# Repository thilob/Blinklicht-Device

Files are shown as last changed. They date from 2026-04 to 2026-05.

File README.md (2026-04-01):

# ESP32 Blaulicht-Controller mit Web-UI & CLI

Dieses Projekt ist ein **Blaulicht-Controller für Modellbau und ähnliche Anwendungen**.  
Die Software läuft auf verschiedenen ESP32-Boards und nutzt die jeweils vorhandenen **LEDC-PWM-Kanäle** der Zielhardware.  

---

## Features

- Bis zur **hardwareabhaengigen LEDC-Grenze** des jeweiligen ESP32-Ziels (PWM, 5 kHz, 8 Bit Helligkeit)  
- **Mehrere Blinkmuster (Patterns)**, die frei definierbar sind  
- **Gruppen-Funktion**: LEDs lassen sich zu Gruppen zusammenfassen und gemeinsam ein-/ausschalten  
- **Phasenverschiebung**: gleiche Muster können zeitlich versetzt starten  
- **Weboberfläche (GUI)**: läuft direkt im Browser (Handy, Tablet, PC), responsive gestaltet  
- **Serielle Konsole (CLI)**: alle Funktionen auch über USB-Terminal steuerbar  
- **Speicherung im Flash** (LittleFS): Konfiguration überlebt Neustarts  
- **WLAN-Betrieb**: Access Point (AP) oder Station (STA, DHCP) mit mDNS (z. B. `http://blaulicht-xxxx.local`)  
- **Captive Portal**: Im AP-Modus wird die Weboberfläche automatisch geöffnet  
- **Brownout-Schutz**: externe Kondensatoren empfohlen (siehe unten)  

---

## Hardware-Aufbau

### ESP32-DevKit
- Verwendet wird ein Standard-ESP32-DevKit (mit USB-Anschluss und Spannungsregler).  

### LED-Ausgänge
- PWM ist nicht auf "ein paar Spezialpins" begrenzt, sondern kann auf viele ausgabefaehige GPIOs gemappt werden.  
- Die eigentliche Grenze ist die Anzahl gleichzeitig verfuegbarer **LEDC-Kanaele** der jeweiligen ESP32-Variante.  
- Das Projekt begrenzt die Standard-Konfiguration automatisch auf die LEDC-Kapazitaet der gewaehlten Zielhardware.  
- Jeder Ausgang steuert eine LED oder LED-Baugruppe.  
- Vor jede LED gehört ein **Vorwiderstand** (typisch 220–470 Ω bei 5 V Betrieb).  

### Versorgung & Brownout-Schutz
Der ESP32 ist empfindlich gegenüber Spannungseinbrüchen („Brownout“).  
Das passiert besonders dann, wenn mehrere LEDs gleichzeitig leuchten oder wenn das WLAN viel Strom zieht.

👉 Deshalb unbedingt folgende Maßnahmen:
- **Ein großer Elektrolytkondensator** (470 µF bis 1000 µF, 6,3 V oder mehr) **zwischen 3,3 V und GND**, möglichst nah am ESP32 bzw. am `3V3`-Pin des Devkits.  
- **Ein Keramikkondensator** (100 nF) direkt am Board bzw. an `3V3`/`GND` als schnelle Stütze.  
- Wenn die Schaltung über USB versorgt wird und die LED-Last die `5V`-Schiene stark belastet, zusätzlich ein weiterer Elko **zwischen `USB 5V` und `GND`** nahe am Devkit oder an der Last.  

So werden Spannungsschwankungen abgefangen und der ESP32 läuft stabil.

---

## Schaltplan (vereinfacht)

### Prinzipdarstellung (ASCII)

```  
USB 5V ----+-----------------------------+
           |                             |
      [DevKit-Regler 3.3V]               |
           |                             |
          3V3 ---+---- ESP32             |
                 |      +-----+-----+    |
             [470uF]    |           |    |
                 |  GPIOx       GPIOy ...|
                GND  |            |      |
                    [R]          [R]     |
                     |            |      |
                    LED          LED     |
                     |            |      |
GND -----------------+------------+------+

Optional bei hoher LED-Last auf USB/5V:

USB 5V ---+--- [zus. Elko 470uF..1000uF] --- GND
```

- `[R]` = Vorwiderstand (220–470 Ω)  
- `[470uF]` = Pufferkondensator zwischen `3.3V` und `GND` gegen Brownouts  
- `[zus. Elko 470uF..1000uF]` = optionaler Puffer zwischen `USB 5V` und `GND`, wenn die `5V`-Versorgung durch LED-Last stark einbricht  

---

## Software-Prinzip

### Patterns (Blinkmuster)
Ein **Pattern** ist eine Liste von Schritten:
- `duration_ms` – Dauer in Millisekunden  
- `level` – Ziel-Helligkeit (0..255)  
- `fade` – weicher Übergang (true) oder harter Sprung (false)  

Beispiel für ein Doppelblitz-Pattern:

```cpp
{30, 255, false},  // LED an
{30,   0, false},  // aus
{30, 255, false},  // LED an
{150, 0,  true},   // langsam ausblenden
{250, 0,  false},  // Pause
```

- Der **letzte Schritt ist die Pause**, bevor das Muster neu startet.  
- Pro Ausgang kann das Pattern individuell gewählt werden.  
- Jeder Ausgang kann zusätzlich eine **Zusatzpause** bekommen, die auf den letzten Schritt des Patterns aufaddiert wird.  

### Gruppen
- Mehrere Ausgänge können zu **Gruppen** zusammengefasst werden.  
- Eine Gruppe kann komplett **ein- oder ausgeschaltet** werden.  
- Ist eine Gruppe aus, bleiben die LEDs dunkel (das Pattern pausiert).  

---

## CLI (Serielle Konsole)

Über USB (115200 Baud) öffnet sich ein Terminal.  
Man sieht, was man tippt (Echo-Funktion ist aktiv).

### Wichtige Befehle:

- `help` → alle Befehle anzeigen  
- `status` → Status von WLAN, Patterns, Gruppen und Ausgängen  
- `wifi on|off` → WLAN/Webserver ein-/ausschalten  
- `mode ap|sta` → WLAN-Modus wählen  
- `sta <ssid> <pass>` → Zugangsdaten für Station-Modus setzen  
- `ap <ssid> [pass]` → SSID/PW für Access Point setzen  
- `dhcp` → im STA-Modus neue DHCP-Adresse beziehen  
- `pat list` → Patterns anzeigen  
- `pat add <name>` → neues Pattern anlegen  
- `pat step add <pidx> <dur> <lvl> <fade>` → Step zu Pattern hinzufügen  
- `group list` → Gruppen anzeigen  
- `group add <id> <name>` → Gruppe anlegen  
- `light list` → Ausgänge anzeigen  
- `light add <pin> <ch> <pidx> <zusatzpause> <gid> <phase>` → Ausgang hinzufügen  

---

## Weboberfläche (GUI)

Die **Web-UI** wird aus dem Flash geladen (`LittleFS`).  
- Im AP-Modus erreichbar unter: `http://192.168.4.1`  
  (Captive Portal öffnet die Seite oft automatisch)  
- Im STA-Modus unter: `http://<hostname>.local` oder über die vergebene DHCP-IP  

### Funktionen:
- WLAN konfigurieren (AP oder STA)  
- Patterns anlegen, bearbeiten, löschen  
- Gruppen verwalten und schalten  
- Ausgänge (Lights) hinzufügen, ändern, löschen  

Die Oberfläche ist **responsive** (Bootstrap-Layout) → funktioniert gut auf Handy, Tablet und PC.  

---

## Build & Flash (PlatformIO)

1. Projekt in **VS Code / PlatformIO** öffnen  
2. **Build** → Firmware kompilieren  
3. **Upload** → ESP32 flashen  
4. **Upload Filesystem Image** → Weboberfläche (index.html) ins LittleFS laden  
5. Serielle Konsole (115200 Baud) starten → Logausgaben prüfen  

### CLI-Beispiele

```bash
# Firmware für ESP32 DevKit V1 / ESP32-WROOM bauen
$HOME/.platformio/penv/bin/pio run -e devkit-v1

# Firmware hochladen
$HOME/.platformio/penv/bin/pio run -e devkit-v1 -t upload

# LittleFS-Image hochladen
$HOME/.platformio/penv/bin/pio run -e devkit-v1 -t uploadfs
```

### Upload-Port / udev-Hinweise unter Linux

Beim Upload kann PlatformIO z. B. folgende Meldungen anzeigen:

```text
Looking for upload port...

Warning! Please install `99-platformio-udev.rules`.
More details: https://docs.platformio.org/en/latest/core/installation/udev-rules.html

Auto-detected: /dev/ttyS0
Uploading .pio/build/devkit-v1/littlefs.bin
esptool.py v4.11.0
Serial port /dev/ttyS0
```

Das bedeutet meist:
- Die empfohlenen PlatformIO-`udev`-Regeln für USB-Seriell-Geräte sind noch nicht installiert.
- PlatformIO hat vermutlich den falschen Port erkannt.
- `/dev/ttyS0` ist oft **nicht** der USB-Port des ESP32, sondern eine interne serielle Schnittstelle des PCs.

Prüfe in so einem Fall die tatsächlich vorhandenen USB-Ports, z. B.:

```bash
ls /dev/ttyUSB* /dev/ttyACM* 2>/dev/null
```

Und gib den Upload-Port dann explizit an:

```bash
$HOME/.platformio/penv/bin/pio run -e devkit-v1 -t upload --upload-port /dev/ttyUSB0
$HOME/.platformio/penv/bin/pio run -e devkit-v1 -t uploadfs --upload-port /dev/ttyUSB0
```

Wenn du unter Linux häufiger Upload-Probleme oder Zugriffsfehler auf serielle Geräte hast, installiere die PlatformIO-`udev`-Regeln:
- Doku: https://docs.platformio.org/en/latest/core/installation/udev-rules.html

### Richtigen Port beim Einstecken finden

Wenn unklar ist, welches Device zu deinem ESP32 gehört, öffne vor dem Einstecken ein Kernel-Log:

```bash
journalctl -k -f
```

Alternativ:

```bash
dmesg --follow
```

Stecke dann den ESP32 an. Typische Meldungen nennen danach den neu angelegten Port, z. B.:

```text
cdc_acm 1-1.3:1.0: ttyACM0: USB ACM device
```

oder:

```text
ch341-uart converter now attached to ttyUSB0
```

Diesen Port kannst du anschließend direkt für Upload und Monitor verwenden:

```bash
$HOME/.platformio/penv/bin/pio run -e devkit-v1 -t upload --upload-port /dev/ttyACM0
$HOME/.platformio/penv/bin/pio device monitor --port /dev/ttyACM0 --baud 115200
```

---

## Fazit

Mit diesem Projekt erhältst du eine **flexible Steuerung für Modellbau-Blaulichter**:  
- Komfortabel über **Web-GUI**  
- Alternativ robust über **CLI**  

Dank externer **Pufferkondensatoren** läuft der ESP32 stabil, auch wenn mehrere LEDs gleichzeitig blinken.  
Die Software ist modular aufgebaut und lässt sich leicht erweitern.

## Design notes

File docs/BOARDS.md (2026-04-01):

# Board-Konfigurationssystem

## Übersicht

Dieses Projekt unterstützt verschiedene ESP32-Boards mit unterschiedlichen Pin-Konfigurationen. Die Board-Konfiguration erfolgt automatisch basierend auf dem gewählten PlatformIO Environment. Die maximal gleichzeitig nutzbaren PWM-Ausgaenge richten sich nach den LEDC-Kanaelen der jeweiligen ESP32-Zielhardware.

## Unterstützte Boards

### ESP32 DevKit (Standard)
- **Environment:** `esp32dev`
- **Alias:** `devkit-v1`
- **Vorkonfigurierte Ausgänge:** 10 LEDs
- **Max. gleichzeitige PWM-Kanaele:** 16
- **Pins:** GPIO 16, 17, 18, 19, 21, 22, 23, 25, 26, 27
- **Reset Pin:** GPIO 34

### ESP32-C3 DevKit M1
- **Environment:** `esp32-c3-devkitm-1`
- **Vorkonfigurierte Ausgänge:** 8 LEDs
- **Max. gleichzeitige PWM-Kanaele:** 8
- **Pins:** GPIO 2, 3, 4, 5, 6, 7, 8, 9
- **Reset Pin:** GPIO 10
- **Hinweis:** GPIO 0,1 für USB reserviert

### ESP32-C3 Super Mini
- **Environment:** `esp32c3-super-mini`
- **Vorkonfigurierte Ausgänge:** 8 LEDs
- **Max. gleichzeitige PWM-Kanaele:** 8
- **Pins:** GPIO 2, 3, 4, 5, 6, 7, 8, 9
- **Reset Pin:** GPIO 10
- **Hinweis:** Sehr kompaktes Board

### WiFiduino32 C3
- **Environment:** `wifiduino32c3`
- **Vorkonfigurierte Ausgänge:** 8 LEDs
- **Hinweis:** 10 Pins sind hinterlegt, aber der ESP32-C3 stellt gleichzeitig nur 8 LEDC-PWM-Kanaele bereit.
- **Pins:** GPIO 2, 3, 4, 5, 6, 7, 8, 9, 10, 18
- **Reset Pin:** GPIO 19

### ESP32-S2 Mini
- **Environment:** `esp32s2-mini`
- **Vorkonfigurierte Ausgänge:** 8 LEDs
- **Hinweis:** 12 Pins sind hinterlegt, gleichzeitig nutzbar sind aber 8 LEDC-PWM-Kanaele.
- **Pins:** GPIO 1-12
- **Reset Pin:** GPIO 0

### ESP32-S3 DevKit
- **Environment:** `esp32s3-devkit`
- **Vorkonfigurierte Ausgänge:** 8 LEDs
- **Hinweis:** 16 Pins sind hinterlegt, gleichzeitig nutzbar sind aber 8 LEDC-PWM-Kanaele.
- **Pins:** GPIO 1-16
- **Reset Pin:** GPIO 0
- **Hinweis:** Mehr GPIOs verfügbar

## Verwendung

### 1. Board auswählen in VS Code

In VS Code unten in der Statusleiste auf das PlatformIO-Symbol klicken und das gewünschte Environment auswählen, z.B. `esp32dev` oder `devkit-v1`.

### 2. Mit PlatformIO CLI

```bash
# ESP32 DevKit kompilieren
pio run -e esp32dev

# ESP32 DevKit V1 (ESP32-WROOM) kompilieren
pio run -e devkit-v1

# ESP32-C3 kompilieren und uploaden
pio run -e esp32-c3-devkitm-1 -t upload

# ESP32-S3 kompilieren und Monitor starten
pio run -e esp32s3-devkit -t upload -t monitor
```

### 3. Board-Info beim Start

Beim Booten zeigt der Serial Monitor die aktuelle Board-Konfiguration:

```
========================================
Blaulicht-Controller (Multi-Board)
========================================
Board:         ESP32 DevKit
LED Ausgänge:  10
LEDC Kanäle:   16
Reset Pin:     GPIO 34
========================================
```

## Eigenes Board hinzufügen

### Schritt 1: Board-Definition in `board_config.h`

```cpp
#elif defined(BOARD_MEIN_BOARD)
  #define BOARD_NAME "Mein Custom Board"

  static const int LED_PINS[] = {
    13, 14, 15, 16, 17, 18  // Deine Pins
  };
  
  static const int RESET_WIFI_PIN = 12;
```

### Schritt 2: Environment in `platformio.ini`

```ini
[env:mein-board]
platform = espressif32
board = esp32dev  ; oder passende Board-ID
framework = arduino
monitor_speed = 115200
board_build.filesystem = littlefs

lib_deps = ${common.lib_deps}

build_flags =
  ${common.base_flags}
  -DBOARD_MEIN_BOARD  ; <-- Wichtig!

lib_ldf_mode = deep+
```

### Schritt 3: Kompilieren

```bash
pio run -e mein-board -t upload
```

## Pin-Auswahl Tipps

### ESP32 (Original)
- ✅ Sicher: GPIO 2, 4, 5, 12-19, 21-23, 25-27, 32-33
- ⚠️ Input-Only: GPIO 34-39 (nur als Eingänge)
- ❌ Vermeiden: GPIO 0, 1 (Boot/Flash), 6-11 (Flash)

### ESP32-C3
- ✅ Sicher: GPIO 2-10, 18-21
- ❌ Vermeiden: GPIO 0, 1 (USB), 18, 19 wenn USB benötigt

### ESP32-S2
- ✅ Sicher: GPIO 1-14, 15-17, 33-42
- ❌ Vermeiden: GPIO 0 (Boot), 19-20 (USB)

### ESP32-S3
- ✅ Viele GPIOs verfügbar
- ❌ Vermeiden: GPIO 19-20 (USB), 26-32 (PSRAM wenn genutzt)

## Beispiel: Migration von einem Board zum anderen

Wenn du von ESP32 DevKit auf ESP32-C3 wechseln möchtest:

1. **Umstecken der Hardware:** Verbinde deine LEDs mit den Pins aus `board_config.h`
2. **Environment wählen:** `esp32-c3-devkitm-1` in PlatformIO
3. **Upload:** Der Code kompiliert automatisch mit den richtigen Pins!
4. **Config prüfen:** Falls du bereits eine `config.json` hast, prüfe ob die Pins stimmen

## Fehlerbehebung

### "Kein Board definiert" Warning
- Stelle sicher dass in `platformio.ini` der richtige `build_flag` gesetzt ist
- Beispiel: `-DBOARD_ESP32_DEVKIT`

### Falscher Pin wird verwendet
- Prüfe die Pin-Definition in `board_config.h`
- Verwende CLI-Befehl `light list` um aktuelle Pins zu sehen

### Brownout-Resets
- Zu viele LEDs für die Stromversorgung
- Verwende externes Netzteil
- Reduziere Anzahl der Ausgänge in `board_config.h`

## Board-IDs Referenz

| Board | PlatformIO board= | Environment Name |
|---|---|---|
| ESP32 DevKit | `esp32dev` | `esp32dev`, `devkit-v1` |
| ESP32-C3 | `esp32-c3-devkitm-1` | `esp32-c3-devkitm-1` |
| ESP32-S2 | `lolin_s2_mini` | `esp32s2-mini` |
| ESP32-S3 | `esp32-s3-devkitc-1` | `esp32s3-devkit` |

Weitere Board-IDs: https://registry.platformio.org/platforms/platformio/espressif32/boards

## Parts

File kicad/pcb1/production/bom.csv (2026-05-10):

Designator | Footprint | Quantity | Value | LCSC Part #
A1 | DOIT_ESP32_DEVKIT_30Pins | 1 | ESP32_DevKit_V1_DOIT_30GPIOs
C1 | C_Radial_D10.0mm_H20.0mm_P5.00mm | 1 | 1000uF
J1 | PinHeader_1x12_P2.54mm_Vertical | 1 | Conn_01x12_Pin
R1 | R_1206 | 1 | 10k
SW1 | SW_Push_SPST_NO_Alps_SKRK | 1 | SW_Push

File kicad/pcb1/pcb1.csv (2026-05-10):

# | Reference | Qty | Value | Footprint | DNP
1 | A1 | 1 | ESP32_DevKit_V1_DOIT_30GPIOs | PCM_SL_Development_Boards:DOIT_ESP32_DEVKIT_30Pins
2 | C1 | 1 | 1000uF | Capacitor_THT:C_Radial_D10.0mm_H20.0mm_P5.00mm
3 | J1 | 1 | Conn_01x12_Pin | Connector_PinHeader_2.54mm:PinHeader_1x12_P2.54mm_Vertical
4 | R1 | 1 | 10k | PCM_fab:R_1206
5 | SW1 | 1 | SW_Push | Button_Switch_SMD:SW_Push_SPST_NO_Alps_SKRK

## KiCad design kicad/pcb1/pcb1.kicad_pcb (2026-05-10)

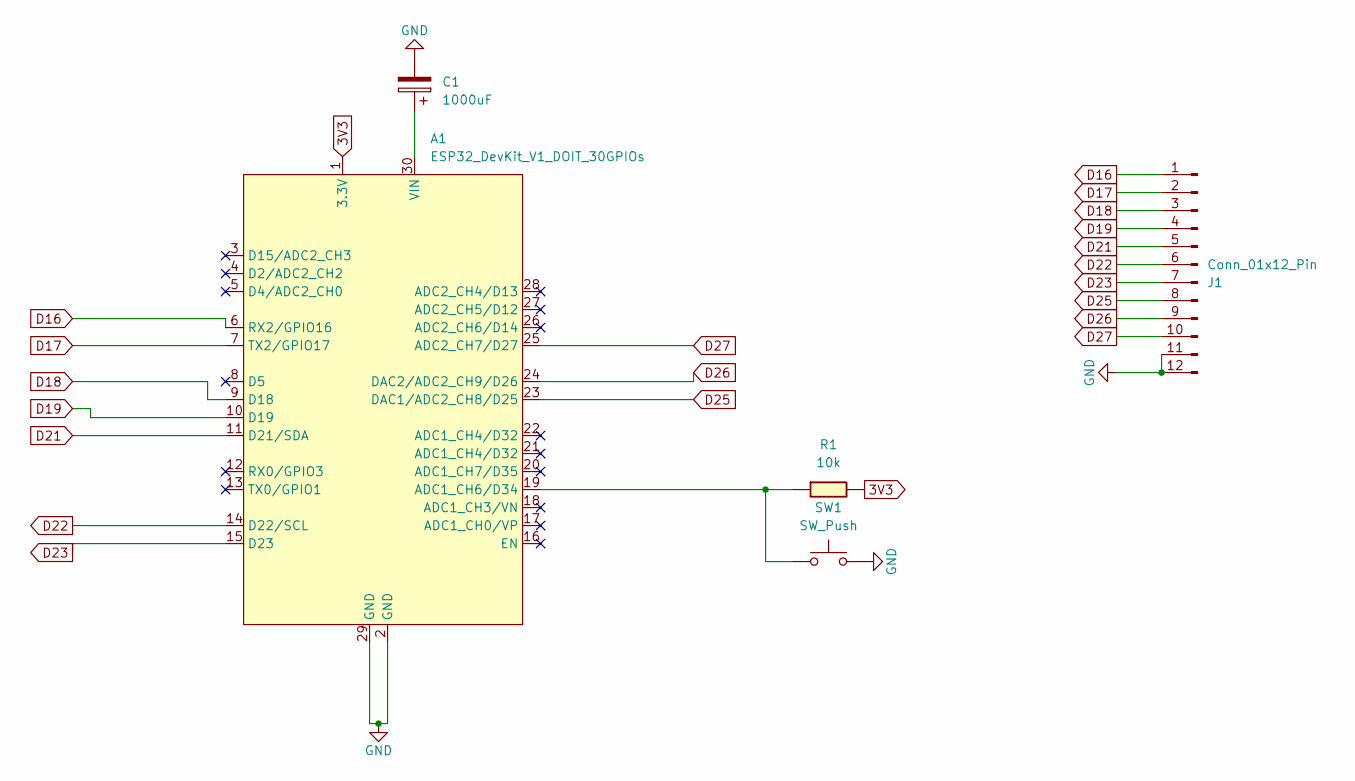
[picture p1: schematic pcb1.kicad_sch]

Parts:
A1: ESP32_DevKit_V1_DOIT_30GPIOs; DOIT_ESP32_DEVKIT_30Pins
C1: 1000uF; C_Radial_D10.0mm_H20.0mm_P5.00mm
J1: Conn_01x12_Pin; PinHeader_1x12_P2.54mm_Vertical
R1: 10k; R_1206
SW1: SW_Push; SW_Push_SPST_NO_Alps_SKRK

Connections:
3V3: A1.1 (3.3V), R1.1
D16: A1.6 (RX2/GPIO16), J1.1
D17: A1.7 (TX2/GPIO17), J1.2
D18: A1.9 (D18), J1.3
D19: A1.10 (D19), J1.4
D21: A1.11 (D21/SDA), J1.5
D22: A1.14 (D22/SCL), J1.6
D23: A1.15 (D23), J1.7
D25: A1.23 (DAC1/ADC2_CH8/D25), J1.8
D26: A1.24 (DAC2/ADC2_CH9/D26), J1.9
D27: A1.25 (ADC2_CH7/D27), J1.10
GND: A1.2 (GND), A1.29 (GND), C1.2, J1.11, J1.12, SW1.2
unnamed: A1.19 (ADC1_CH6/D34), R1.2, SW1.1
unnamed: A1.30 (VIN), C1.1

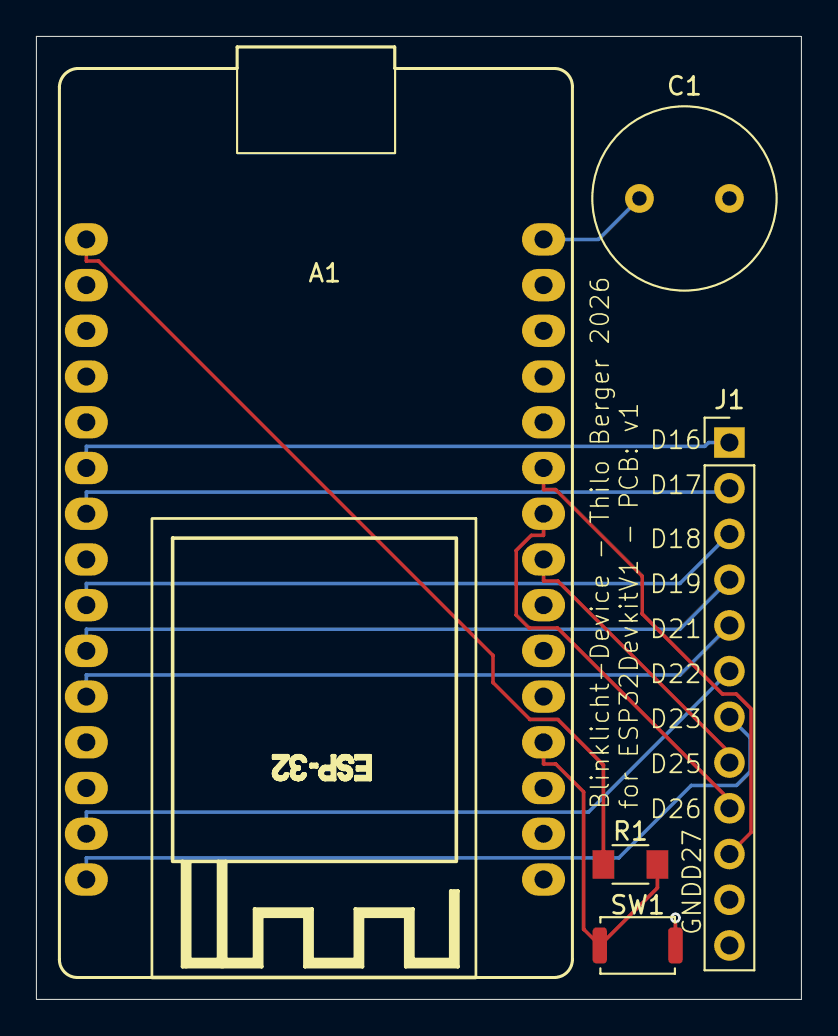
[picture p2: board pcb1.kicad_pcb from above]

Board: 2 copper layers, 42.5 x 53.5 mm, 5 parts (0 on the bottom side), 14 nets.

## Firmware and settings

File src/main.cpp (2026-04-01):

#include <Arduino.h>
#include <WiFi.h>
#include <WebServer.h>
#include <DNSServer.h>
#include <LittleFS.h>
#include <ArduinoJson.h>
#include <FS.h>
#include <esp32-hal-bt.h>
#include <ESPmDNS.h>
#include <soc/rtc_cntl_reg.h>
#include <soc/soc.h>
#include "board_config.h"  // Board-spezifische Pin-Konfiguration

/* =========================================================================
   Blaulicht-Controller (Multi-Board ESP32)
   - Flexible Ausgänge (board-abhängig), PWM (LEDC) 5 kHz / 8-bit, nicht-blockierend
   - Mehrere Patterns (letzter Step = Ruhepause), CRUD via Web-UI (AP/STA) ODER CLI
   - Lights: pin, channel, patternIndex, extraPauseMs, groupId, phase_ms
   - Gruppen an/aus (freeze der Zeit), Phasenverschiebung pro Ausgang
   - Persistenz: /config.json (LittleFS)
   - WLAN: AP (eindeutige SSID + Captive Portal) / STA (DHCP + mDNS Hostname)
   - JsonDocument-API (ArduinoJson v7)
   - NEU: /api/wifi (nur WLAN), /api/config (nur Logik) => getrenntes Anwenden
   - Board-System: Pin-Konfiguration via board_config.h + platformio.ini
   ========================================================================= */

/// -------------------- AP-/Netzwerk-Defaults --------------------
static const IPAddress AP_IP  (192,168,4,1);
static const IPAddress AP_GW  (192,168,4,1);
static const IPAddress AP_MASK(255,255,255,0);

/// -------------------- (Optionale) Gamma-Korrektur --------------------
constexpr bool GAMMA_CORRECTION = false;
static uint8_t gammaTable[256];
static inline uint8_t applyGamma(uint8_t v) {
  if (!GAMMA_CORRECTION) return v;
  return gammaTable[v];
}
static void buildGammaTable() {
  for (int i = 0; i < 256; ++i) {
    float norm = i / 255.0f;
    float gamma = powf(norm, 2.2f);
    gammaTable[i] = (uint8_t)roundf(gamma * 255.0f);
  }
}

/// -------------------- Datenmodelle --------------------
struct LEDStep {
  uint16_t duration_ms;   // Länge des Schritts
  uint8_t  level;         // Zielhelligkeit (0..255)
  bool     fade;          // weicher Übergang über die Dauer
};

struct Pattern {
  String               name;
  std::vector<LEDStep> steps;  // letzter Step = Ruhepause
};

struct GroupCfg {
  int     id;
  String  name;
  bool    enabled;
};

struct LightCfg {
  uint8_t pin;
  uint8_t channel;        // 0..15
  uint8_t patternIndex;   // Index in patterns[]
  int     extraPauseMs;   // -1 => keine Zusatzpause; sonst Zusatzdauer für den letzten Step
  int     groupId;
  int     phase_ms;       // Phasenverschiebung relativ zum Pattern-Zyklus (>=0)
};

static std::vector<Pattern>  patterns;
static std::vector<GroupCfg> groups;
static std::vector<LightCfg> lights;

/// -------------------- WLAN-Config (persistiert) --------------------
static bool   wifiEnabled  = true;    // Hauptschalter
static String wifiModeCfg  = "ap";    // "ap" | "sta"
static String apSsidCfg    = "";      // leer => wird zu "Blaulicht-XXXX"
static String apPassCfg    = "";      // leer => offener AP
static String staSsidCfg   = "";
static String staPassCfg   = "";
static String hostName     = "";      // mDNS/Hostname (z. B. "blaulicht-xxxx")

static WebServer server(80);
static bool serverRunning = false;
// Captive-DNS (nur im AP-Modus aktiv)
static DNSServer dnsServer;
// Flag für verzögerten WiFi-Neustart (Race Condition vermeiden)
static volatile bool wifiRestartPending = false;
// Flag für Setup-Phase (verhindert vorzeitige Player-Updates)
static bool systemReady = false;

/// -------------------- Helpers --------------------
static bool isGroupEnabled(int gid) {
  for (const auto &g : groups) if (g.id == gid) return g.enabled;
  return true; // unbekannte Gruppe => nicht blockieren
}

static String uniqueMacSuffix() {
  uint8_t mac[6]; WiFi.macAddress(mac);
  char buf[7]; snprintf(buf, sizeof(buf), "%02X%02X%02X", mac[3], mac[4], mac[5]);
  return String(buf);
}
static String makeDefaultApSsid() {
  return String("Blaulicht-") + uniqueMacSuffix();
}
static void sanitizeHostName(String &hn) {
  hn.toLowerCase();
  for (size_t i=0;i<hn.length();++i) {
    char c=hn[i];
    if (!((c>='a'&&c<='z')||(c>='0'&&c<='9')||c=='-')) hn.setCharAt(i,'-');
  }
  while (hn.startsWith("-")) hn.remove(0,1);
  while (hn.endsWith("-")) hn.remove(hn.length()-1);
  if (!hn.length()) hn = "esp32";
}

/// -------------------- Player für EINEN Ausgang --------------------
class PatternPlayer {
public:
  PatternPlayer() = default;

  void attach(uint8_t ledcChannel) { ch = ledcChannel; }
  void bind(int lightIndex) { boundLightIndex = lightIndex; }

  void begin() {
    prev = 0;
    idx = 0;
    started = millis();
    lastDt = 0;
    initialized = false;
  }

  void update() {
    if (!isValidBinding()) return;

    const LightCfg &L = lights[boundLightIndex];
    if ((size_t)L.patternIndex >= patterns.size()) { writeLevel(0); return; }
    const Pattern &P = patterns[L.patternIndex];
    if (P.steps.empty()) { writeLevel(0); return; }

    if (!initialized) {
      initWithPhase(L, P);
      initialized = true;
    }

    if (!isGroupEnabled(L.groupId)) {
      writeLevel(0);
      started = millis() - lastDt; // freeze
      return;
    }

    const LEDStep &s = P.steps[idx];
    const uint16_t dur = effectiveDuration(L, P, idx, s.duration_ms);

    const uint32_t now = millis();
    lastDt = now - started;

    if (lastDt >= dur) {
      writeLevel(target);
      nextStep(L, P);
      return;
    }

    const float t = dur > 0 ? (float)lastDt / (float)dur : 1.0f;
    uint8_t cur = s.fade
      ? (uint8_t)roundf(prev + (float)((int)target - (int)prev) * t)
      : target;
    writeLevel(cur);
  }

private:
  uint8_t ch = 0;
  int     boundLightIndex = -1;

  bool     initialized = false;
  size_t   idx = 0;
  uint32_t started = 0;
  uint32_t lastDt  = 0;
  uint8_t  prev = 0;
  uint8_t  target = 0;

  inline void writeLevel(uint8_t lvl) { ledcWrite(ch, applyGamma(lvl)); }

  bool isValidBinding() const {
    return boundLightIndex >= 0 && (size_t)boundLightIndex < lights.size();
  }

  static size_t restIndexOf(const Pattern &P) {
    return P.steps.empty() ? 0 : (P.steps.size() - 1);
  }

  static uint16_t effectiveDuration(const LightCfg &L, const Pattern &P, size_t i, uint16_t nominal) {
    if (i == restIndexOf(P) && L.extraPauseMs >= 0) {
      return (uint16_t)min<uint32_t>(65535UL, (uint32_t)nominal + (uint32_t)L.extraPauseMs);
    }
    return nominal;
  }

  static uint32_t patternTotalMs(const LightCfg &L, const Pattern &P) {
    uint32_t total = 0;
    for (size_t i = 0; i < P.steps.size(); ++i)
      total += effectiveDuration(L, P, i, P.steps[i].duration_ms);
    return total;
  }

  void initWithPhase(const LightCfg &L, const Pattern &P) {
    uint32_t total = patternTotalMs(L, P);
    uint32_t phase = (L.phase_ms >= 0 && total > 0) ? (uint32_t)L.phase_ms % total : 0;

    size_t step = 0; uint32_t acc = 0;
    while (step < P.steps.size()) {
      uint16_t dur = effectiveDuration(L, P, step, P.steps[step].duration_ms);
      if (phase < acc + dur) break;
      acc += dur; ++step;
    }
    if (step >= P.steps.size()) step = 0;

    idx = step;
    const LEDStep &s = P.steps[idx];
    prev = P.steps[ idx == 0 ? (P.steps.size()-1) : (idx-1) ].level;
    target = s.level;
    if (!s.fade) writeLevel(target);

    started = millis() - (phase - acc);
    lastDt  = (phase - acc);
  }

  void nextStep(const LightCfg &L, const Pattern &P) {
    prev = target;
    idx = (idx + 1) % P.steps.size();
    const LEDStep &s = P.steps[idx];
    target = s.level;
    if (!s.fade) writeLevel(target);
    started = millis();
    lastDt = 0;
  }
};

static std::vector<PatternPlayer> players;

/// -------------------- Persistenz --------------------
static bool saveConfig() {
  File f = LittleFS.open("/config.json", FILE_WRITE);
  if (!f) return false;

  JsonDocument doc;

  // wifi
  JsonObject jw = doc["wifi"].to<JsonObject>();
  jw["enabled"] = wifiEnabled;
  jw["mode"]    = wifiModeCfg; // "ap" | "sta"
  JsonObject jwa = jw["ap"].to<JsonObject>();
  jwa["ssid"]     = apSsidCfg.length() ? apSsidCfg : makeDefaultApSsid();
  jwa["password"] = apPassCfg;
  JsonObject jws = jw["sta"].to<JsonObject>();
  jws["ssid"]     = staSsidCfg;
  jws["password"] = staPassCfg;

  // patterns
  JsonArray jPatterns = doc["patterns"].to<JsonArray>();
  for (const auto &p : patterns) {
    JsonObject jp = jPatterns.add<JsonObject>();
    jp["name"] = p.name;
    JsonArray jSteps = jp["steps"].to<JsonArray>();
    for (const auto &st : p.steps) {
      JsonObject js = jSteps.add<JsonObject>();
      js["duration_ms"] = st.duration_ms;
      js["level"]       = st.level;
      js["fade"]        = st.fade;
    }
  }
  // groups
  JsonArray jGroups = doc["groups"].to<JsonArray>();
  for (const auto &g : groups) {
    JsonObject jg = jGroups.add<JsonObject>();
    jg["id"] = g.id; jg["name"] = g.name; jg["enabled"] = g.enabled;
  }
  // lights
  JsonArray jLights = doc["lights"].to<JsonArray>();
  for (const auto &L : lights) {
    JsonObject jl = jLights.add<JsonObject>();
    jl["pin"]            = L.pin;
    jl["channel"]        = L.channel;
    jl["patternIndex"]   = L.patternIndex;
    jl["extraPauseMs"]   = L.extraPauseMs;
    jl["groupId"]        = L.groupId;
    jl["phase_ms"]       = L.phase_ms;
  }

  bool ok = serializeJsonPretty(doc, f) > 0;
  f.close();
  return ok;
}

static bool loadConfig() {
  if (!LittleFS.exists("/config.json")) return false;
  File f = LittleFS.open("/config.json", FILE_READ);
  if (!f) return false;

  JsonDocument doc;
  DeserializationError err = deserializeJson(doc, f);
  f.close();
  if (err) return false;

  // WLAN
  wifiEnabled = (bool)(doc["wifi"]["enabled"] | true);
  wifiModeCfg = String(doc["wifi"]["mode"]    | "ap");
  if (doc["wifi"]["ap"].is<JsonObject>()) {
    apSsidCfg = String(doc["wifi"]["ap"]["ssid"]     | "");
    apPassCfg = String(doc["wifi"]["ap"]["password"] | "");
  }
  if (doc["wifi"]["sta"].is<JsonObject>()) {
    staSsidCfg= String(doc["wifi"]["sta"]["ssid"]     | "");
    staPassCfg= String(doc["wifi"]["sta"]["password"] | "");
  }

  patterns.clear(); groups.clear(); lights.clear();

  for (JsonObject jp : doc["patterns"].as<JsonArray>()) {
    Pattern p; p.name = jp["name"].as<const char*>();
    for (JsonObject js : jp["steps"].as<JsonArray>()) {
      LEDStep st;
      st.duration_ms = (uint16_t)(js["duration_ms"] | 0);
      st.level       = (uint8_t) (js["level"]       | 0);
      st.fade        = (bool)    (js["fade"]        | false);
      p.steps.push_back(st);
    }
    patterns.push_back(std::move(p));
  }

  for (JsonObject jg : doc["groups"].as<JsonArray>()) {
    GroupCfg g;
    g.id      = (int)(jg["id"]      | 0);
    g.name    = jg["name"].as<const char*>();
    g.enabled = (bool)(jg["enabled"] | true);
    groups.push_back(std::move(g));
  }

  for (JsonObject jl : doc["lights"].as<JsonArray>()) {
    LightCfg L;
    L.pin            = (uint8_t)(jl["pin"]            | 255);
    L.channel        = (uint8_t)(jl["channel"]        | 0);
    L.patternIndex   = (uint8_t)(jl["patternIndex"]   | 0);
    if (!jl["extraPauseMs"].isNull())      L.extraPauseMs = (int)(jl["extraPauseMs"] | -1);
    else                                   L.extraPauseMs = (int)(jl["restOverrideMs"] | -1);
    L.groupId        = (int)     (jl["groupId"]       | 0);
    L.phase_ms       = (int)     (jl["phase_ms"]      | 0);
    lights.push_back(std::move(L));
  }
  return true;
}

static void makeDefaultConfig() {
  wifiEnabled = true;
  wifiModeCfg = "ap";
  apSsidCfg   = "";     // automatisch "Blaulicht-XXXX"
  apPassCfg   = "";     // offen
  staSsidCfg  = "";
  staPassCfg  = "";

  patterns.clear(); groups.clear(); lights.clear();

  // Default-Patterns aus dem aktuellen Live-Stand des Devkits übernehmen
  {
    Pattern p; p.name = "Pat0-Blaulicht_Dreifachblitz";
    LEDStep s[] = {
      {30,255,false},{30,0,false},{30,255,false},{30,0,false},
      {150,255,false},{30,0,true},{30,255,false},{0,0,false},{250,0,false}
    };
    p.steps.assign(std::begin(s), std::end(s));
    patterns.push_back(std::move(p));
  }
  {
    Pattern p; p.name = "Pat1-DoppelStrobeWeich";
    LEDStep s[] = { {60,255,true},{40,0,true},{60,255,true},{40,0,true},{180,0,false} };
    p.steps.assign(std::begin(s), std::end(s));
    patterns.push_back(std::move(p));
  }
  {
    Pattern p; p.name = "Drehspiegel";
    LEDStep s[] = { {120,255,true},{500,0,false} };
    p.steps.assign(std::begin(s), std::end(s));
    patterns.push_back(std::move(p));
  }
  {
    Pattern p; p.name = "Xenonblitzer einfach";
    LEDStep s[] = { {30,255,false},{300,0,false} };
    p.steps.assign(std::begin(s), std::end(s));
    patterns.push_back(std::move(p));
  }
  {
    Pattern p; p.name = "Xenonblitz doppelt";
    LEDStep s[] = { {30,255,false},{100,0,false},{30,255,false},{300,0,false} };
    p.steps.assign(std::begin(s), std::end(s));
    patterns.push_back(std::move(p));
  }

  groups.push_back({0,"Front",true});
  groups.push_back({1,"Heck", true});

  // Automatisch Lights basierend auf Board-Konfiguration erstellen
  lights.clear();
  for (size_t i = 0; i < DEFAULT_LED_OUTPUTS; ++i) {
    LightCfg L;
    L.pin = LED_PINS[i];
    L.channel = (uint8_t)i;
    L.patternIndex = (i % 2 == 0) ? 0 : 1;  // Abwechselnd Pattern 0 und 1
    L.extraPauseMs = -1;
    L.groupId = (i < DEFAULT_LED_OUTPUTS / 2) ? 0 : 1;  // Vordere Hälfte = Front, Rest = Heck
    L.phase_ms = (int)(i * 50);  // Phasenverschiebung
    lights.push_back(L);
  }
}

/// Hardware Setup (nur LEDC, keine Player-Initialisierung)
static void setupHardware() {
  Serial.println("Initialisiere LEDs schrittweise (Brownout-Schutz)...");
  for (const auto &L : lights) {
    if (L.channel >= MAX_LEDC_CHANNELS) continue;
    ledcSetup(L.channel, LEDC_FREQ_HZ, LEDC_RES_BITS);
    ledcAttachPin(L.pin, L.channel);
    ledcWrite(L.channel, 0);
    delay(10);  // Brownout-Schutz: Stromspitzen vermeiden
  }
  Serial.println("LEDs initialisiert.");
}

/// Player binden & starten (getrennt von Hardware-Setup)
static void startPlayers() {
  players.clear();
  players.reserve(min<size_t>(lights.size(), MAX_LEDC_CHANNELS));

  for (size_t i = 0; i < lights.size(); ++i) {
    if (lights[i].channel >= MAX_LEDC_CHANNELS) continue;
    PatternPlayer player;
    player.attach(lights[i].channel);
    player.bind((int)i);
    player.begin();
    players.push_back(std::move(player));
  }
}

/// Hardware anwenden (LEDC setup/attach) + Player binden & (re)starten
static void applyHardware() {
  setupHardware();
  startPlayers();
}

/// -------------------- Static Files --------------------
static String contentTypeFor(const String& path) {
  if (path.endsWith(".html")) return "text/html; charset=utf-8";
  if (path.endsWith(".css"))  return "text/css; charset=utf-8";
  if (path.endsWith(".js"))   return "application/javascript; charset=utf-8";
  if (path.endsWith(".json")) return "application/json; charset=utf-8";
  if (path.endsWith(".ico"))  return "image/x-icon";
  if (path.endsWith(".png"))  return "image/png";
  if (path.endsWith(".jpg") || path.endsWith(".jpeg")) return "image/jpeg";
  if (path.endsWith(".svg"))  return "image/svg+xml; charset=utf-8";
  return "text/plain; charset=utf-8";
}
static bool handleFileRead(String path) {
  if (path.endsWith("/")) path += "index.html";
  if (!LittleFS.exists(path)) return false;
  File f = LittleFS.open(path, "r");
  if (!f) return false;
  server.streamFile(f, contentTypeFor(path));
  f.close();
  return true;
}

/// -------------------- CORS / Captive / JSON helper --------------------
static void addCORS() {
  server.sendHeader("Access-Control-Allow-Origin", "*");
  server.sendHeader("Access-Control-Allow-Methods", "GET,POST,PUT,DELETE,OPTIONS");
  server.sendHeader("Access-Control-Allow-Headers", "Content-Type, Accept");
}
static void sendJSON(const String &json) {
  server.sendHeader("Cache-Control", "no-store");
  addCORS();
  server.send(200, "application/json; charset=utf-8", json);
}
static bool isAPModeActive() {
  return (wifiEnabled && wifiModeCfg == "ap" && WiFi.getMode() == WIFI_AP);
}

// Captive-Portal: nur für HTML, nie für API
static bool handleCaptivePortalRedirect()
{
  const String uri = server.uri();
  if (uri.startsWith("/api/")) return false;
  const String accept = server.header("Accept");
  if (accept.indexOf("application/json") >= 0) return false;
  if (!isAPModeActive()) return false;

  IPAddress ip = WiFi.softAPIP();
  String host = server.hostHeader(); host.toLowerCase();
  if (host != ip.toString()) {
    server.sendHeader("Location", String("http://") + ip.toString() + "/");
    server.send(302, "text/plain", "");
    return true;
  }
  return false;
}

/// -------------------- REST Endpoints --------------------
// --- Vollständige Konfiguration lesen (für UI) ---
static void handleGetConfig() {
  if (wifiRestartPending) { server.send(503, "text/plain", "Server restarting"); return; }
  JsonDocument doc;

  // WLAN
  JsonObject jw = doc["wifi"].to<JsonObject>();
  jw["enabled"] = wifiEnabled;
  jw["mode"]    = wifiModeCfg;
  JsonObject jwa = jw["ap"].to<JsonObject>();
  jwa["ssid"]     = apSsidCfg.length()?apSsidCfg:makeDefaultApSsid();
  jwa["password"] = apPassCfg;
  JsonObject jws = jw["sta"].to<JsonObject>();
  jws["ssid"]     = staSsidCfg;
  jws["password"] = staPassCfg;

  // patterns
  JsonArray jPatterns = doc["patterns"].to<JsonArray>();
  for (const auto &p : patterns) {
    JsonObject jp = jPatterns.add<JsonObject>();
    jp["name"] = p.name;
    JsonArray jSteps = jp["steps"].to<JsonArray>();
    for (const auto &st : p.steps) {
      JsonObject js = jSteps.add<JsonObject>();
      js["duration_ms"] = st.duration_ms;
      js["level"]       = st.level;
      js["fade"]        = st.fade;
    }
  }
  // groups
  JsonArray jGroups = doc["groups"].to<JsonArray>();
  for (const auto &g : groups) {
    JsonObject jg = jGroups.add<JsonObject>();
    jg["id"] = g.id; jg["name"] = g.name; jg["enabled"] = g.enabled;
  }
  // lights
  JsonArray jLights = doc["lights"].to<JsonArray>();
  for (const auto &L : lights) {
    JsonObject jl = jLights.add<JsonObject>();
    jl["pin"]            = L.pin;
    jl["channel"]        = L.channel;
    jl["patternIndex"]   = L.patternIndex;
    jl["extraPauseMs"]   = L.extraPauseMs;
    jl["groupId"]        = L.groupId;
    jl["phase_ms"]       = L.phase_ms;
  }

  String out; serializeJson(doc, out);
  sendJSON(out);
}

// --- NUR Logik speichern (keine WLAN-Änderung / kein WLAN-Restart) ---
static void handlePutConfig() {
  if (wifiRestartPending) { server.send(503, "text/plain", "Server restarting"); return; }
  if (!server.hasArg("plain")) { addCORS(); server.send(400, "text/plain", "Missing body"); return; }
  JsonDocument doc;
  DeserializationError err = deserializeJson(doc, server.arg("plain"));
  if (err) { addCORS(); server.send(400, "text/plain", String("JSON error: ")+err.c_str()); return; }

  // Pflicht: patterns/groups/lights
  if (!doc["patterns"].is<JsonArray>() || !doc["lights"].is<JsonArray>() || !doc["groups"].is<JsonArray>()) {
    addCORS(); server.send(400,"text/plain","Invalid JSON structure (patterns/groups/lights required)"); return;
  }

  // KEINE WLAN-Felder anfassen.
  patterns.clear(); groups.clear(); lights.clear();

  for (JsonObject jp : doc["patterns"].as<JsonArray>()) {
    Pattern p; p.name = jp["name"].as<const char*>();
    for (JsonObject js : jp["steps"].as<JsonArray>()) {
      LEDStep st;
      st.duration_ms = (uint16_t)(js["duration_ms"] | 0);
      st.level       = (uint8_t) (js["level"]       | 0);
      st.fade        = (bool)    (js["fade"]        | false);
      p.steps.push_back(st);
    }
    patterns.push_back(std::move(p));
  }
  for (JsonObject jg : doc["groups"].as<JsonArray>()) {
    GroupCfg g;
    g.id      = (int)(jg["id"]      | 0);
    g.name    = jg["name"].as<const char*>();
    g.enabled = (bool)(jg["enabled"] | true);
    groups.push_back(std::move(g));
  }
  for (JsonObject jl : doc["lights"].as<JsonArray>()) {
    LightCfg L;
    L.pin            = (uint8_t)(jl["pin"]            | 255);
    L.channel        = (uint8_t)(jl["channel"]        | 0);
    L.patternIndex   = (uint8_t)(jl["patternIndex"]   | 0);
    if (!jl["extraPauseMs"].isNull())      L.extraPauseMs = (int)(jl["extraPauseMs"] | -1);
    else                                   L.extraPauseMs = (int)(jl["restOverrideMs"] | -1);
    L.groupId        = (int)     (jl["groupId"]       | 0);
    L.phase_ms       = (int)     (jl["phase_ms"]      | 0);
    lights.push_back(std::move(L));
  }

  // Nur Logik anwenden
  applyHardware();

  // Speichern (inkl. unveränderter WLAN-Felder)
  bool ok = saveConfig();

  addCORS(); server.send(ok?200:500, "text/plain", ok?"OK (saved, no wifi restart)":"ERROR (save failed)");
}
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
void loop() {
  // WiFi-Neustart außerhalb von HTTP-Handler-Kontext
  if (wifiRestartPending) {
    wifiRestartPending = false;
    systemReady = false;  // Player während WiFi-Restart pausieren
    Serial.println("[WiFi] Restarting WiFi/Server...");
    delay(250);  // Letzte Responses aussenden
    stopWiFi();  // Erst stoppen
    delay(250);  // Stop abwarten
    if (wifiEnabled) startWiFi();
    systemReady = true;   // System wieder bereit
    return;  // Diesen Loop-Durchlauf beenden, kein handleClient() mehr
  }

  if (serverRunning) {
    if (isAPModeActive()) dnsServer.processNextRequest(); // Captive DNS
    server.handleClient();
  }

  if (systemReady) {
    for (auto &player : players) player.update();
  }

  cliPoll();
}

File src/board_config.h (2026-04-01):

#pragma once

#include <soc/soc_caps.h>

/// ============================================================================
/// Board-spezifische Pin-Konfigurationen
/// Wird via build_flags in platformio.ini definiert
/// ============================================================================

// -------------------- ESP32 DevKit (Standard 30-Pin) --------------------
#ifdef BOARD_ESP32_DEVKIT
  #define BOARD_NAME "ESP32 DevKit"
  
  static const int LED_PINS[] = {
    16, 17, 18, 19, 21, 22, 23, 25, 26, 27
  };
  
  static const int RESET_WIFI_PIN = 34;  // Input only
  
// -------------------- ESP32-C3 Super Mini (13 GPIO) --------------------
#elif defined(BOARD_ESP32C3_MINI)
  #define BOARD_NAME "ESP32-C3 Super Mini"
  
  static const int LED_PINS[] = {
    2, 3, 4, 5, 6, 7, 8, 9  // GPIO 0,1 für USB; 18,19 für andere
  };
  
  static const int RESET_WIFI_PIN = 10;

// -------------------- ESP32-C3 WiFiduino (21 GPIO) --------------------
#elif defined(BOARD_WIFIDUINO32C3)
  #define BOARD_NAME "WiFiduino32 C3"
  
  static const int LED_PINS[] = {
    2, 3, 4, 5, 6, 7, 8, 9, 10, 18
  };
  
  static const int RESET_WIFI_PIN = 19;

// -------------------- ESP32-S2 Mini --------------------
#elif defined(BOARD_ESP32S2_MINI)
  #define BOARD_NAME "ESP32-S2 Mini"
  
  static const int LED_PINS[] = {
    1, 2, 3, 4, 5, 6, 7, 8, 9, 10, 11, 12
  };
  
  static const int RESET_WIFI_PIN = 0;

// -------------------- ESP32-S3 DevKit --------------------
#elif defined(BOARD_ESP32S3_DEVKIT)
  #define BOARD_NAME "ESP32-S3 DevKit"
  
  static const int LED_PINS[] = {
    1, 2, 3, 4, 5, 6, 7, 8, 9, 10, 11, 12, 13, 14, 15, 16
  };
  
  static const int RESET_WIFI_PIN = 0;

// -------------------- Custom Board (Beispiel für eigene Definition) --------------------
#elif defined(BOARD_CUSTOM)
  #define BOARD_NAME "Custom Board"
  
  static const int LED_PINS[] = {
    13, 14, 15, 16, 17, 18  // Deine eigenen Pins
  };
  
  static const int RESET_WIFI_PIN = 12;

// -------------------- Fallback: Standard ESP32 --------------------
#else
  #warning "Kein Board definiert, verwende ESP32 DevKit als Standard"
  #define BOARD_NAME "ESP32 DevKit (Default)"
  
  static const int LED_PINS[] = {
    16, 17, 18, 19, 21, 22, 23, 25, 26, 27
  };
  
  static const int RESET_WIFI_PIN = 34;
#endif

// -------------------- Validierung --------------------
constexpr size_t BOARD_LED_PIN_COUNT = sizeof(LED_PINS) / sizeof(LED_PINS[0]);

#ifdef SOC_LEDC_SUPPORT_HS_MODE
constexpr uint8_t MAX_LEDC_CHANNELS = SOC_LEDC_CHANNEL_NUM * 2;
#else
constexpr uint8_t MAX_LEDC_CHANNELS = SOC_LEDC_CHANNEL_NUM;
#endif

constexpr size_t DEFAULT_LED_OUTPUTS =
  (BOARD_LED_PIN_COUNT < MAX_LEDC_CHANNELS) ? BOARD_LED_PIN_COUNT : MAX_LEDC_CHANNELS;

static_assert(BOARD_LED_PIN_COUNT > 0, "Mindestens ein LED-Pin muss definiert sein.");

// -------------------- Gemeinsame Konstanten --------------------
constexpr uint32_t LEDC_FREQ_HZ = 5000;
constexpr uint8_t LEDC_RES_BITS = 8;

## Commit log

2025-09-28 v5 mit acht Ausgängen und variablen Pattern
2025-09-30 korrigierte Main.cpp, so dass keine littlefs-Fehler mehr auftreten sollten.
    [main.cpp]
2025-09-30 eindeutiger WLAN-Name wird im AP-Modus erzeugt (MAC-Adresse wird teilweise verwendet)
2025-09-30 Version mit Hardware-Reset an GPIO 32
    [main.cpp]
2025-09-30 speichern und ausführen-Funktion so angepasst, dass beim Speichern von nicht-WLAN-Daten kein Neustart oder keine Änderung der WLAN-Daten eintritt.
2025-10-01 verbesserte Readme-Datei und Hilfetexte in der Weboberfläche.
2025-11-29 ESP32C3 aufgenommen.
2025-12-14 vor einführung board config system
2025-12-14 nach einführung board config system
2026-03-15 Fix PlatformIO board compatibility check
    [main.cpp]
2026-03-31 Add ESP32 DevKit V1 environment and upload docs
2026-03-31 Fix wifi save and apply endpoints
    [main.cpp]
2026-04-01 Fix /api/wifi payload parsing
    [main.cpp]
2026-04-01 Make PWM limits hardware-aware
2026-05-09 Kicad-PCB hinzugefügt.
    [pcb1.kicad_pcb, pcb1.kicad_sch]
2026-05-10 BOM aufgenommen
    [pcb1.csv, pcb1.kicad_pcb]
2026-05-10 nach Versand an JLCPCB
    [bom.csv, designators.csv, positions.csv]
2026-05-10 added Pin Desc
    [pcb1.kicad_pcb]
